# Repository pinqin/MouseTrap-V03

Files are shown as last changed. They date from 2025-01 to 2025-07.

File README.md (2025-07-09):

# MouseTrap-V03
ESP32 Pico D4 Board with 
- VSPI-Connector
- SMA antenna Connector
- 3 Switches ...
  - IO0 (ESP32)
  - EN (ESP32)
  - MOD (Free to use)
- SD-Card Slot

Bildschirmfoto 2025-01-17 um 22 12 02

Bildschirmfoto 2025-01-17 um 22 11 45





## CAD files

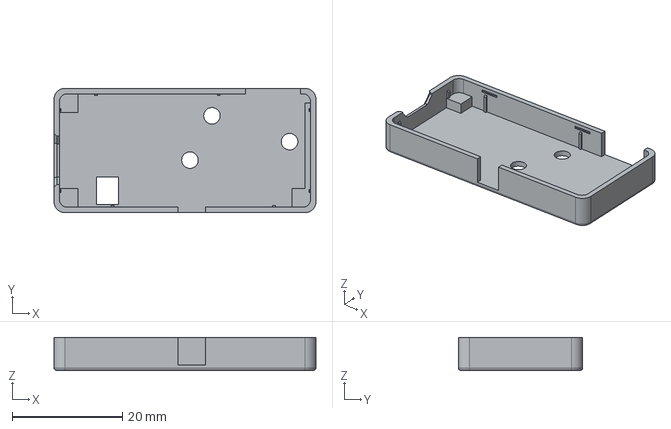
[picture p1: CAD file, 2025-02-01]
Housing/Druck/Unterteil-Körper.step
47.6 x 22.6 x 6.00 mm

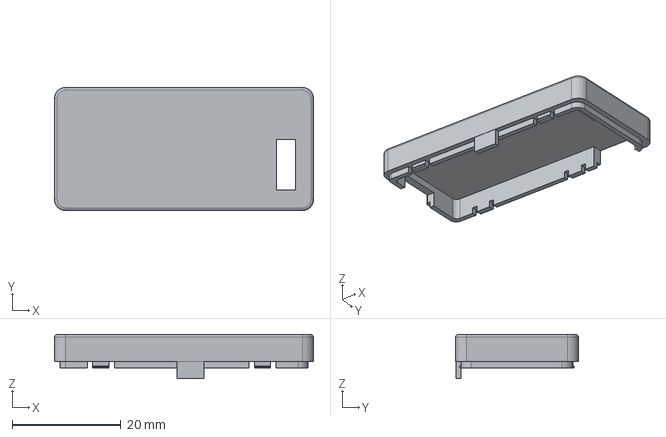
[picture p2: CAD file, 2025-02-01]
Housing/Druck/Oberteil-Body.step
47.6 x 22.6 x 8.10 mm

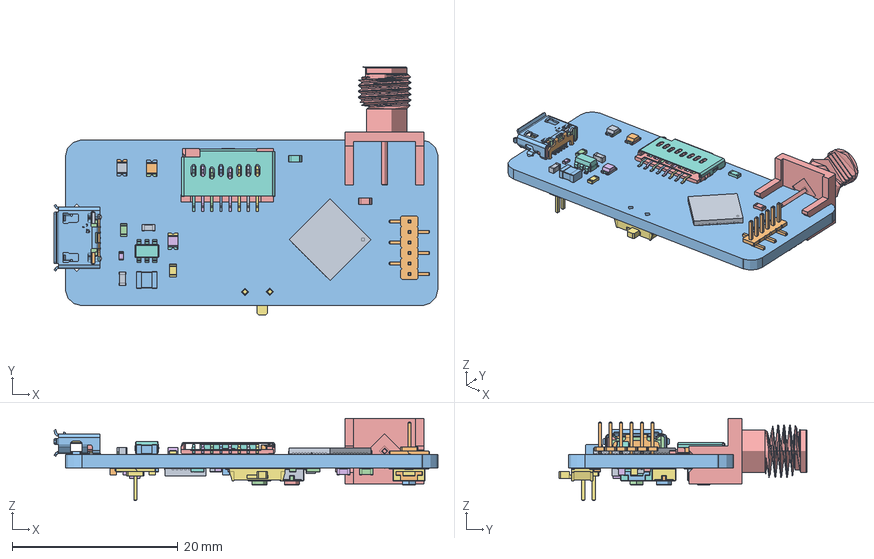
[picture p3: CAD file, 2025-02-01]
Housing/PCBA.FCStd
46.4 x 29.9 x 9.94 mm
C_0603_1608Metric
HSMG-C170
HSMG-C171
HSMG-C172
HSMG-C173
HSMG-C176
HSMG-C177
HSMG-C178
HSMG-C179
SOT_23_6
QFN-48-1EP_7x7mm_Pitch0.5mm
PinHeader_1x06_P127mm_Vertical_SMD_Pin1Left
L_1008_2520Metric
R_0603_1608Metric
R_0603_1608Metric002
HSMG-C182
HSMG-C183
HSMG-C184
HSMG-C185
SMA_Molex_73251-1153_EdgeMount_Horizontal
R_0402_1005Metric
R_0603_1608Metric004
R_0603_1608Metric006
C_0603_1608Metric002
SP0503BAHTG
SP0503BAHTG001
SP0503BAHTG002
SP0503BAHTG003
SP0503BAHTG004
Fusion_sp
SOT_563
QFN-28-1EP_5x5mm_Pitch0.5mm
C_0603_1608Metric004
R_0603_1608Metric008
C_0603_1608Metric006
R_0603_1608Metric010
R_0603_1608Metric012
SKRKAEE020
SKRKAEE021
SKRKAEE022
SKRKAEE023
SKRKAEE024
R_0603_1608Metric014
R_0603_1608Metric016
C_0603_1608Metric008
C_0603_1608Metric010
R_0603_1608Metric018
SKRKAEE027
SKRKAEE028
SKRKAEE029
SKRKAEE030
SKRKAEE031
C_0603_1608Metric012
C_0603_1608Metric014
SKRKAEE034
SKRKAEE035
SKRKAEE036
SKRKAEE037
SKRKAEE038
R_0603_1608Metric020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

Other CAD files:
Housing/Baugruppe_MouseTrap_V01.FCStd
Housing/Unterteil.FCStd
Housing/Oberteil.FCStd
Housing/Druck/Oberteil-Body.stl
Housing/Druck/Unterteil-Körper.stl

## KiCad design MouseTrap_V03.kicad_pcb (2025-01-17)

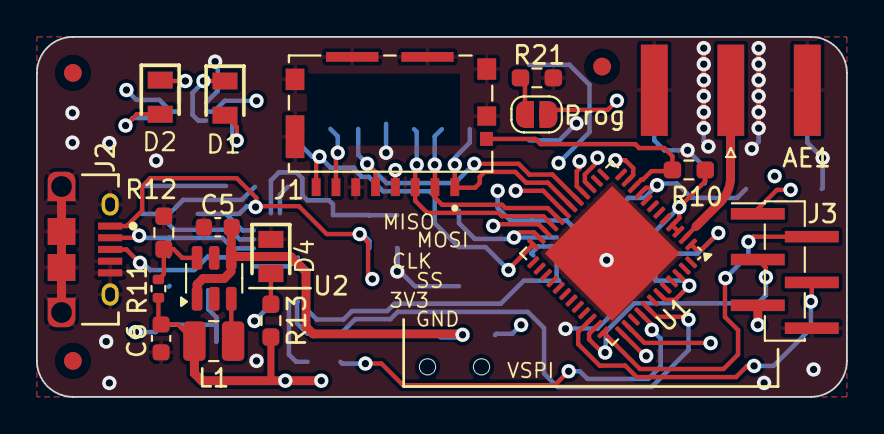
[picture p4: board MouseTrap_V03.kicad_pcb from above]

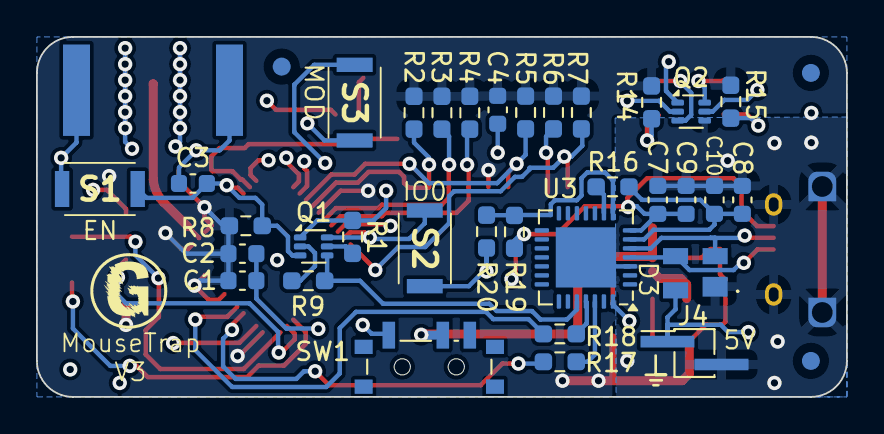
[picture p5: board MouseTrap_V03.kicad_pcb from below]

Board: 4 copper layers, 45.0 x 20.0 mm, 57 parts (36 on the bottom side), 42 nets.

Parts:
AE1: Antenna_Shield; SMA_Amphenol_132289_EdgeMount
C1, C4: 10µF X5R 25V; C_0603_1608Metric
C2, C3, C7, C8: 100nF; C_0603_1608Metric
C5, C6: 22µ; C_0603_1608Metric
C9, C10: 4.7µF; C_0603_1608Metric
D1: HSMG-C170; LEDC2012X80N
D2: HSMB-C170; LEDC2012X80N
D3: SP0503BAHTG
D4: HSMS-C170; LEDC2012X80N
FID1, FID2, FID3, FID4, FID5, FID6: Fiducial; Fiducial_1mm_Mask2mm
J1: 1051620001
J2: 10118194-0001LF; Amphenol_ICC-10118194-0001LF-MFG
J3: Conn_01x06_Socket; PinHeader_1x06_P1.27mm_Vertical_SMD_Pin1Left
J4: Conn_01x02_Pin; PinHeader_1x02_P1.27mm_Vertical_SMD_Pin1Left
JP1: Jumper_2_Open; SolderJumper-2_P1.3mm_Open_RoundedPad1.0x1.5mm
L1: 2µ2; L_1008_2520Metric
Q1, Q2: DMN63D8LV-7; SOT-563
R1, R9: 2K2; R_0603_1608Metric_Pad0.98x0.95mm_HandSolder
R2, R3, R4, R5, R6, R7, R8, R10: 10K; R_0603_1608Metric_Pad0.98x0.95mm_HandSolder
R11: 450K; R_0402_1005Metric
R12: 100K; R_0603_1608Metric_Pad0.98x0.95mm_HandSolder
R13, R14, R15, R17, R18, R21: 1K; R_0603_1608Metric_Pad0.98x0.95mm_HandSolder
R16: 4K7; R_0603_1608Metric_Pad0.98x0.95mm_HandSolder
R19: 22K6; R_0603_1608Metric_Pad0.98x0.95mm_HandSolder
R20: 47K; R_0603_1608Metric_Pad0.98x0.95mm_HandSolder
S1, S2, S3: SKRKAEE020
SW1: SW_DIP_x01; SW_SPDT_PCM12
U1: ESP32-PICO-D4; QFN-48-1EP_7x7mm_P0.5mm_EP5.3x5.3mm
U2: MT3420C-mt3420c; SOT-23-6
U3: CP2102N-Axx-xQFN28; QFN-28-1EP_5x5mm_P0.5mm_EP3.35x3.35mm

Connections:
ChangeModi: S3.1, U1.11 (IO35)
DTR: Q1.1 (S2), R1.2, U3.28 (~DTR)
EN: C3.2, Q1.3 (D1), R8.1, S1.1, U1.9 (EN)
EN_LED_BLUE: Q2.2 (G2), U1.15 (IO26)
EN_LED_GREEN: Q2.5 (G1), U1.16 (IO27)
ESD_K1: D3.2 (K_1), J2.2, U3.5 (D-)
ESD_K2: D3.3 (K_2), J2.3, U3.4 (D+)
ESD_K3: C7.2, C9.2, D3.4 (K_3), J2.1, J4.1, R19.1, SW1.1, U3.7 (VREGIN)
GND: AE1.2 (Shield), C1.2, C2.2, C3.1, C4.2, C5.2, C6.2, C7.1, C8.2, C9.1, C10.2, D3.1 (COMMON_A), D4.1, J1.6 (VSS), J1.10 (GND), J1.11 (GND), J1.12 (SHIELD), J1.13 (SHIELD), J1.14 (GND), J1.15 (GND), J2.4, J2.5, J2.6 (MNT_1), J2.7 (MNT_2), J2.8 (MNT_3), J2.9 (MNT_4), J2.10 (MNT_5), J2.11 (MNT_6), J3.6, J4.2, Q2.1 (S2), Q2.4 (S1), R12.2, R20.2, R21.1, S1.2, S2.2, S3.2, U1.49 (GND), U2.2 (GND), U3.3 (GND), U3.29 (GND)
GPIO0: Q1.6 (D2), S2.1, U1.23 (IO0)
unnamed: AE1.1 (A), U1.2 (LNA_IN)
unnamed: D1.2 (A), R14.2
unnamed: D1.1 (K), Q2.3 (D1)
unnamed: D2.2 (A), R15.2
unnamed: D2.1 (K), Q2.6 (D2)
unnamed: D4.2, R13.1
unnamed: JP1.1 (A), R21.2
unnamed: Q1.5 (G1), R1.1
unnamed: Q1.2 (G2), R9.1
unnamed: C5.1, SW1.2, U2.1 (EN), U2.4 (IN)
unnamed: R11.2, R12.1, U2.6 (FB)
unnamed: L1.1, U2.3 (SW)
unnamed: R18.1, U3.25 (RXD)
unnamed: R17.1, U3.26 (TXD)
unnamed: C8.1, C10.1, R16.1, U3.6 (VDD)
unnamed: R16.2, U3.9 (~RST)
RTS: Q1.4 (S1), R9.2, U3.24 (~RTS)
RXD0: R17.2, U1.40 (U0RXD/IO3)
SD0: J1.7 (DAT0), JP1.2 (B), R6.1, U1.22 (IO2)
SD1: J1.8 (DAT1), R7.1, U1.24 (IO4)
SD2: J1.1 (DAT2), R2.1, U1.18 (IO12)
SD3: J1.2 (DAT3/CD), R3.1, U1.20 (IO13)
SD_CD: J1.9 (DET), R10.1, U1.10 (IO34)
SD_CLK: J1.5 (CLK), R5.1, U1.17 (IO14)
SD_CMD: J1.3 (CMD), R4.1, U1.21 (IO15)
TXD0: R18.2, U1.41 (U0TXD/IO1)
VBUS: R19.2, R20.1, U3.8 (VBUS)
VDD 3V3: C1.1, C2.1, C4.1, C6.1, J1.4 (VDD), J3.5, L1.2, R2.2, R3.2, R4.2, R5.2, R6.2, R7.2, R8.2, R10.2, R11.1, R13.2, R14.1, R15.1, U1.1 (VDDA), U1.3 (VDDA3P3), U1.4 (VDDA3P3), U1.19 (VDD3P3_RTC), U1.37 (VDD3P3_CPU), U1.43 (VDDA), U1.46 (VDDA)
VSPI_MISO: J3.1, U1.38 (IO19)
VSPI_MOSI: J3.2, U1.36 (IO23)
VSPI_SCLK: J3.3, U1.35 (IO18)
VSPI_SS: J3.4, U1.34 (IO5)
